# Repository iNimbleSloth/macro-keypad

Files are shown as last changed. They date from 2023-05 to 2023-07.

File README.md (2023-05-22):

# macro-keypad
A small USB macro keypad designed to use Cherry MX or pin compatible switches.

Here’s an accompanying video showing the macro keypad in more detail.

See the use, design and coding on [YouTube](https://www.youtube.com/watch?v=2TVdBebZfKo)
MacroKeypad_square
2023-05-21-14 40 29_square

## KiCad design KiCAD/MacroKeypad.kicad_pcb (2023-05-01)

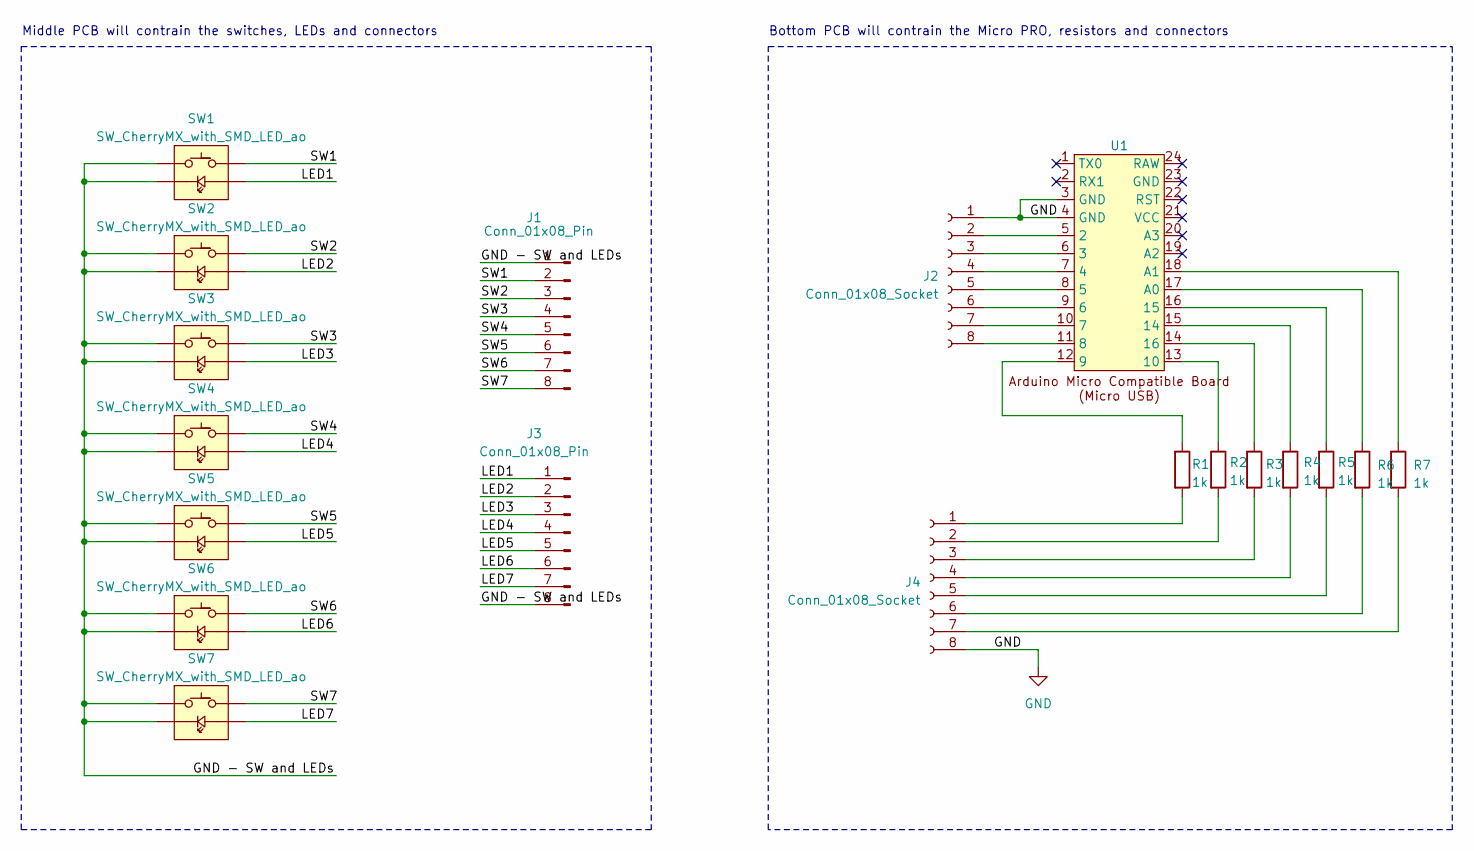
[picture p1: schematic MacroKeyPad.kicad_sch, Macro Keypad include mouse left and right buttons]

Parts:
J1, J3: Conn_01x08_Pin; PinHeader_1x08_P2.54mm_Vertical
J2, J4: Conn_01x08_Socket; PinSocket_1x08_P2.54mm_Vertical
R1, R2, R3, R4, R5, R6, R7: 1k; R_Axial_DIN0207_L6.3mm_D2.5mm_P10.16mm_Horizontal
SW1, SW2, SW3, SW4, SW5, SW6, SW7: SW_CherryMX_with_SMD_LED_ao; SW_Cherry_MX_1.00u_PCB_with SMD LED.kicad_AO
U1: ArduinoMicroCompatibleBoard

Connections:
/GND - SW and LEDs: J1.1, J3.8, SW1.1, SW1.3 (K), SW2.1, SW2.3 (K), SW3.1, SW3.3 (K), SW4.1, SW4.3 (K), SW5.1, SW5.3 (K), SW6.1, SW6.3 (K), SW7.1, SW7.3 (K)
/LED1: J3.1, SW1.4 (A)
/LED2: J3.2, SW2.4 (A)
/LED3: J3.3, SW3.4 (A)
/LED4: J3.4, SW4.4 (A)
/LED5: J3.5, SW5.4 (A)
/LED6: J3.6, SW6.4 (A)
/LED7: J3.7, SW7.4 (A)
/SW1: J1.2, SW1.2
/SW2: J1.3, SW2.2
/SW3: J1.4, SW3.2
/SW4: J1.5, SW4.2
/SW5: J1.6, SW5.2
/SW6: J1.7, SW6.2
/SW7: J1.8, SW7.2
GND: J2.1, J4.8, U1.3 (GND), U1.4 (GND)
unnamed: J2.2, U1.5 (2)
unnamed: J2.3, U1.6 (3)
unnamed: J2.4, U1.7 (4)
unnamed: J2.5, U1.8 (5)
unnamed: J2.6, U1.9 (6)
unnamed: J2.7, U1.10 (7)
unnamed: J2.8, U1.11 (8)
unnamed: J4.1, R1.2
unnamed: J4.2, R2.2
unnamed: J4.3, R3.2
unnamed: J4.4, R4.2
unnamed: J4.5, R5.2
unnamed: J4.6, R6.2
unnamed: J4.7, R7.2
unnamed: R1.1, U1.12 (9)
unnamed: R2.1, U1.13 (10)
unnamed: R4.1, U1.15 (14)
unnamed: R5.1, U1.16 (15)
unnamed: R3.1, U1.14 (16)
unnamed: R6.1, U1.17 (A0)
unnamed: R7.1, U1.18 (A1)

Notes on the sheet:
Bottom PCB will contrain the Micro PRO, resistors and connectors
Middle PCB will contrain the switches, LEDs and connectors

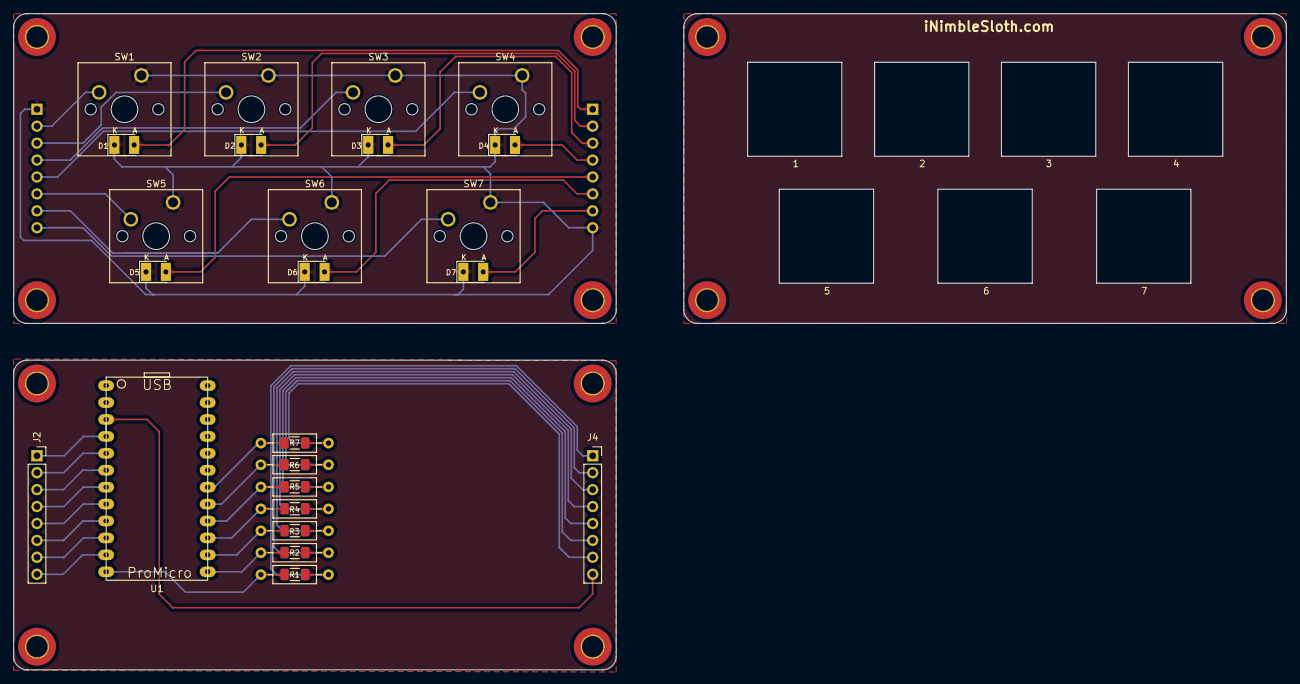
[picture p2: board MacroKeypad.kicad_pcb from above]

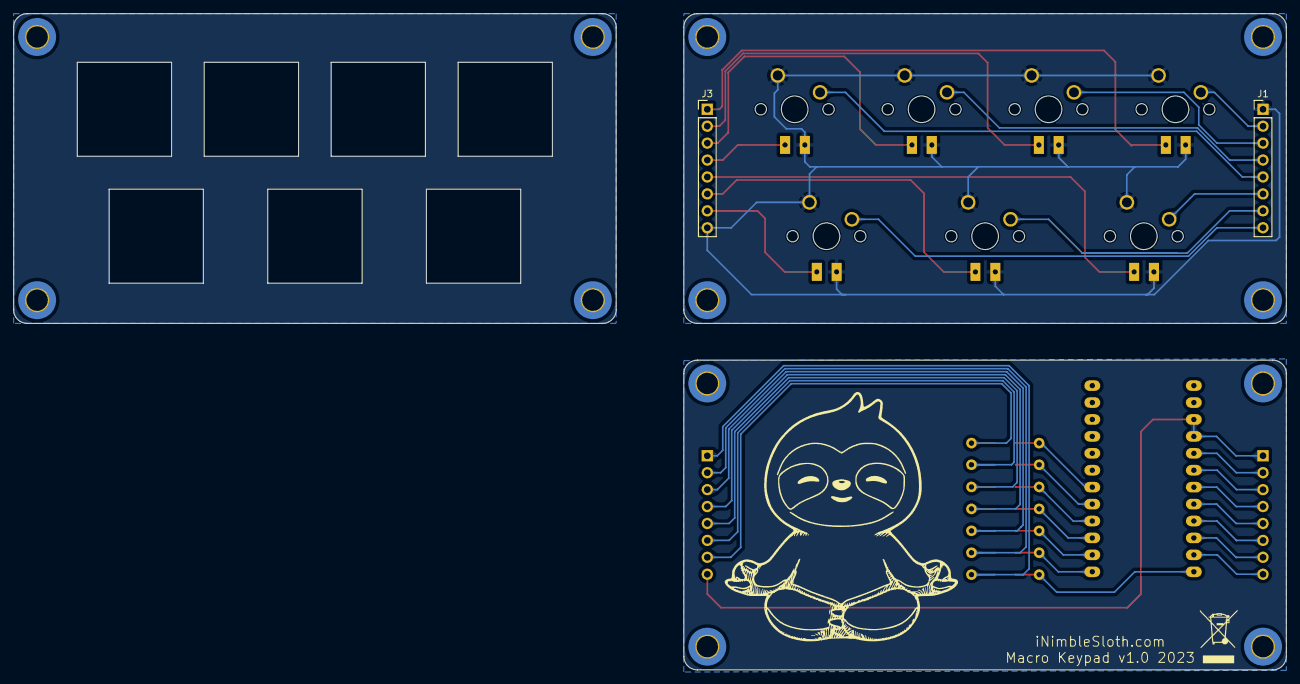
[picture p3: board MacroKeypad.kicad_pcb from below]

Board: 2 copper layers, 191.0 x 98.5 mm, 19 parts (2 on the bottom side), 37 nets.

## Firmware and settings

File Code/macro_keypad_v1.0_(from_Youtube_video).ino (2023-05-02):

 /*  Macro Keypad
  by iNimbleSloth.com
  April 2023
*/
#include <Keyboard.h>
#include <Mouse.h>

//Create names for I/O; SW for input switches & led for LEDs in the switches.
//The Number is the Arduino pin out NOT the PCB pinout!!
int sw1 = 2;
int sw2 = 3;
int sw3 = 4;
int sw4 = 5;
int sw5 = 6;
int sw6 = 7;
int sw7 = 8;
int led1 = 9;
int led2 = 10;
int led3 = 16;
int led4 = 14;
int led5 = 15;
int led6 = 18;
int led7 = 19;

// variables to keep strack of button states
bool copyState = false;       // set initial state of Copy to false, i.e copy key not held down
bool pasteState = false;      // set initial state of paste to false, i.e copy key not held down
bool sw1State = false;        // set initial sate of sw1 to false
bool sw2State = false;        // set initial sate of sw2 to false
bool sw3State = false;        // set initial sate of sw3 to false
bool sw4State = false;        // set initial sate of sw4 to false
//bool sw5State = false;        // set initial sate of sw5 to false
//bool sw6State = false;        // set initial sate of sw6 to false
bool sw7State = false;        // set initial sate of sw7 to false

void setup() {

  Serial.begin(9600);           //serial output used for debugging (not required for release version)

  //setup I/O; SW inputs with internal pull up resistor. LEDs as outputs.
  pinMode(sw1, INPUT_PULLUP);
  pinMode(sw2, INPUT_PULLUP);
  pinMode(sw3, INPUT_PULLUP);
  pinMode(sw4, INPUT_PULLUP);
  pinMode(sw5, INPUT_PULLUP);
  pinMode(sw6, INPUT_PULLUP);
  pinMode(sw7, INPUT_PULLUP);
  pinMode(led1, OUTPUT);
  pinMode(led2, OUTPUT);
  pinMode(led3, OUTPUT);
  pinMode(led4, OUTPUT);
  pinMode(led5, OUTPUT);
  pinMode(led6, OUTPUT);
  pinMode(led7, OUTPUT);
}

//Main program loop starts here.
void loop() {
  //Serial.println("Start of Loop ");

  //SW1
  // IF SW1 is pressed AND the sw1State status is false (i.e. not already pressed), then type text
  if (digitalRead(sw1) == LOW && sw1State == false)
  {
    digitalWrite(led1, HIGH);
    sw1State = true;
    Keyboard.println("Case ");
    Keyboard.println("Create cLibrary acount and add username to contact in Salesforce.");
    Keyboard.println("Send through new technical contact lead.");
    delay(50);
  }
    
  // IF SW1 is released AND the sw3State status is true (i.e. button just released), then turn off the LED on the  button (SW1/LED1)
  if (digitalRead(sw1) == HIGH && sw1State == true)
  {
    digitalWrite(led1, LOW);
    sw1State = false;
    delay(50);
  }
    
  //SW2
  // IF SW2 is pressed AND the sw4State status is false (i.e. not already pressed), then type text
  if (digitalRead(sw2) == LOW && sw2State == false)
  {
    digitalWrite(led2, HIGH);
    sw2State = true;
    Keyboard.println("Created cLibrary acount and added username to contact in Salesforce.");
    Keyboard.println("Sent through new technical contact lead.");
    delay(50);
  }
    
  // IF SW4 is released AND the sw2State status is true (i.e. button just released), then turn off the LED on the snip button (SW2/LED2)
  if (digitalRead(sw2) == HIGH && sw2State == true)
  {
    digitalWrite(led2, LOW);
    sw2State = false;
    delay(50);
  }

  //SW3
  // IF SW3 is pressed and the sw5State status is false (i.e. not already pressed), then press type text
  if (digitalRead(sw3) == LOW && sw3State == false)
  {
    digitalWrite(led3, HIGH);
    sw3State = true;
    Keyboard.println("Case ");
    Keyboard.println("Create academy account.");
    Keyboard.println("Send lead through to quote for training.");
    delay(50);
  }
    
  // IF SW3 is released AND the snipeState status is true (i.e. button just released), then turn off the LED on the snip button (SW5/LED5)
  if (digitalRead(sw3) == HIGH && sw3State == true)
  {
    digitalWrite(led3, LOW);
    sw3State = false;
    delay(50);
  }

  //SW4 
  // IF SW4 is pressed and the sw4State status is false (i.e. not already pressed), then press type text
  if (digitalRead(sw4) == LOW && sw4State == false)
  {
    digitalWrite(led4, HIGH);
    sw4State = true;
    Keyboard.println("Created academy account.");
    Keyboard.println("Sent lead through to quote for training.");
    delay(50);
  }
    
  // IF SW4 is released AND the snipeState status is true (i.e. button just released), then turn off the LED on the snip button (SW4/LED4)
  if (digitalRead(sw4) == HIGH && sw4State == true)
  {
    digitalWrite(led4, LOW);
    sw4State = false;
    delay(50);
  }
    
  //SW5
  // IF SW5 is pressed and the copyState status is false (i.e. not already pressed), then execute Windows COPY command
  if (digitalRead(sw5) == LOW && copyState == false)
  {
    digitalWrite(led5, HIGH);
    copyState = true;
    Serial.println("Windows COPY command START");
    Keyboard.press(KEY_LEFT_CTRL);
    Keyboard.write('c');
    Keyboard.release(KEY_LEFT_CTRL);
    delay(50);
  }
    
  // IF SW5 is released AND the copyState status is true (i.e. button just released), then turn off the LED on the COPY button (SW5/LED5)
  if (digitalRead(sw5) == HIGH && copyState == true)
  {
    digitalWrite(led5, LOW);
    copyState = false;
    Serial.println("Windows COPY command END");
    delay(50);
  }

  //SW6 
  // IF SW6 is pressed AND the pasteState status is false (i.e. not already pressed), then execute Windows PASTE command
  if (digitalRead(sw6) == LOW && pasteState == false)
  {
    digitalWrite(led6, HIGH);
    pasteState = true;
    Serial.println("Windows PASTE command START");
    Keyboard.press(KEY_LEFT_CTRL);
    Keyboard.write('v');
    Keyboard.release(KEY_LEFT_CTRL);
    delay(50);
  }
    
  // IF SW6 is released AND the pasteState status is true (i.e. button just released), then turn off the LED on the PASTE button (SW3/LED3)
  if (digitalRead(sw6) == HIGH && pasteState == true)
  {
    digitalWrite(led6, LOW);
    pasteState = false;
    Serial.println("Windows PASTE command END");
    delay(50);
  }

  // IF SW7 is pressed and the sw7State status is false (i.e. not already pressed), then press execuste Windows DESKTOP command
  if (digitalRead(sw7) == LOW && sw7State == false)
  {
    digitalWrite(led7, HIGH);
    sw7State = true;
    Serial.println("Windows Desktop command START");
    Keyboard.press(KEY_LEFT_GUI);
    Keyboard.write('d');
    Keyboard.release(KEY_LEFT_GUI);
    delay(50);
  }

  // IF SW7 is NOT pressed and the rightClick status is true (i.e. the button has just been released), then release the right mouse button
  if(digitalRead(sw7) == HIGH && sw7State == true)
  {
    digitalWrite(led7, LOW);
    sw7State = false;
    delay(50);
  }

}

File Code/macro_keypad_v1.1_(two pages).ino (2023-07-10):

 /*  Macro Keypad
  by iNimbleSloth.com
  April 2023
*/
#include <Keyboard.h>
#include <Mouse.h>

//Create names for I/O; SW for input switches & led for LEDs in the switches.
//The Number is the Arduino pin out NOT the PCB pinout!!
int sw1 = 2;
int sw2 = 3;
int sw3 = 4;
int sw4 = 5;
int sw5 = 6;
int sw6 = 7;
int sw7 = 8;
int led1 = 9;
int led2 = 10;
int led3 = 16;
int led4 = 14;
int led5 = 15;
int led6 = 18;
int led7 = 19;

// variables to keep strack of button states
bool sw1State = false;        // set initial state of sw1 to false
bool sw2State = false;        // set initial state of sw2 to false
bool sw3State = false;        // set initial state of sw3 to false
bool sw4State = false;        // set initial state of sw4 to false
bool sw5State = false;   	  // set initial state of sw5 to false
bool sw6State = false;        // set initial state of sw6 to false
bool sw7State = false;        // set initial state of sw7 to false
bool page2Status = false;     // set initial state of Page 2 to false (this is a specical case used in toggle function of the button)
int currentSW7State;          // to keep track of the current state of button 7 (special case used in toggle function of the button)
int lastSW7State;             // to keep track of the last state of button 7 (special case used in toggle function of the button)


void setup() {

  Serial.begin(9600);           //serial output used for debugging (not required for release version)

  //setup I/O; SW inputs with internal pull up resistor. LEDs as outputs.
  pinMode(sw1, INPUT_PULLUP);
  pinMode(sw2, INPUT_PULLUP);
  pinMode(sw3, INPUT_PULLUP);
  pinMode(sw4, INPUT_PULLUP);
  pinMode(sw5, INPUT_PULLUP);
  pinMode(sw6, INPUT_PULLUP);
  pinMode(sw7, INPUT_PULLUP);
  pinMode(led1, OUTPUT);
  pinMode(led2, OUTPUT);
  pinMode(led3, OUTPUT);
  pinMode(led4, OUTPUT);
  pinMode(led5, OUTPUT);
  pinMode(led6, OUTPUT);
  pinMode(led7, OUTPUT);
  
  // read in current states of the switches (specical case for SW7 as being used to toggle the state of CTRL)
  currentSW7State = digitalRead(sw7);
}

//Main program loop starts here.
void loop() {
  //Serial.println("Start of Loop ");
  
  lastSW7State = currentSW7State;       //save the last state of button 7
  currentSW7State = digitalRead(sw7);   //read in the current state of button 7

  //SW1
  // IF SW1 is pressed AND the sw1State status is false (i.e. not already pressed), then type text
  if (digitalRead(sw1) == LOW && sw1State == false)
  {
    if (page2Status != true)
    {
      //Serial.println("Page 1 Button 1");
      digitalWrite(led1, HIGH);
      sw1State = true;
      //ENTER YOUR KEYBOARD SHORT CUT FOR PAGE 1 HERE
    }
    else
    {
      //Serial.println("Page 2 Button 1");
      digitalWrite(led1, HIGH);
      sw1State = true;
      //ENTER YOUR KEYBOARD SHORT CUT FOR PAGE 2 HERE

      
    }
    delay(50);
  }
    
  // IF SW1 is released AND the sw3State status is true (i.e. button just released), then turn off the LED on the  button (SW1/LED1)
  if (digitalRead(sw1) == HIGH && sw1State == true)
  {
    digitalWrite(led1, LOW);
    sw1State = false;
    delay(50);
  }
    
  //SW2
  // IF SW2 is pressed AND the sw4State status is false (i.e. not already pressed), then type text
  if (digitalRead(sw2) == LOW && sw2State == false)
  {
    if (page2Status != true)
    {
      //Serial.println("Page 1 Button 2");
      digitalWrite(led2, HIGH);
      sw2State = true;
      //ENTER YOUR KEYBOARD SHORT CUT FOR PAGE 1 HERE

    }
     else
    {
      //Serial.println("Page 2 Button 2");
      digitalWrite(led2, HIGH);
      sw2State = true;
      //ENTER YOUR KEYBOARD SHORT CUT FOR PAGE 2 HERE
    }
    delay(50);
  }
    
  // IF SW2 is released AND the sw2State status is true (i.e. button just released), then turn off the LED on the snip button (SW2/LED2)
  if (digitalRead(sw2) == HIGH && sw2State == true)
  {
    digitalWrite(led2, LOW);
    sw2State = false;
    delay(50);
  }

  //SW3
  // IF SW3 is pressed and the sw5State status is false (i.e. not already pressed), then press type text
  if (digitalRead(sw3) == LOW && sw3State == false)
  {
    if (page2Status != true)
    {
      //Serial.println("Page 1 Button 3");
      digitalWrite(led3, HIGH);
      sw3State = true;
      //ENTER YOUR KEYBOARD SHORT CUT FOR PAGE 1 HERE

      
    }
    else
    {
      //Serial.println("Page 2 Button 3");
      digitalWrite(led3, HIGH);
      sw3State = true;
      //ENTER YOUR KEYBOARD SHORT CUT FOR PAGE 2 HERE
      
    }
    delay(50);
  }
    
  // IF SW3 is released AND the snipeState status is true (i.e. button just released), then turn off the LED on the snip button (SW5/LED5)
  if (digitalRead(sw3) == HIGH && sw3State == true)
  {
    digitalWrite(led3, LOW);
    sw3State = false;
    delay(50);
  }

  //SW4 
  // IF SW4 is pressed and the sw4State status is false (i.e. not already pressed), then press type text
  if (digitalRead(sw4) == LOW && sw4State == false)
  {
    if (page2Status != true)
    {
      //Serial.println("Page 1 Button 4");
      digitalWrite(led4, HIGH);
      sw4State = true;
      //ENTER YOUR KEYBOARD SHORT CUT FOR PAGE 1 HERE
    }
    else
    {
      //Serial.println("Page 2 Button 4");
      digitalWrite(led4, HIGH);
      sw4State = true;
      //ENTER YOUR KEYBOARD SHORT CUT FOR PAGE 2 HERE
    }
    delay(50);
  }
    
  // IF SW4 is released AND the snipeState status is true (i.e. button just released), then turn off the LED on the snip button (SW4/LED4)
  if (digitalRead(sw4) == HIGH && sw4State == true)
  {
    digitalWrite(led4, LOW);
    sw4State = false;
    delay(50);
  }
    
  //SW5
  // IF SW5 is pressed and the sw5State status is false (i.e. not already pressed), then execute Windows COPY command
  if (digitalRead(sw5) == LOW && sw5State == false)
  {
    if (page2Status != true || true)  // FOR MY MACROPAD BUTTON 5 should do the same for both pages
    {
      //Serial.println("Page 1 Button 5");
      digitalWrite(led5, HIGH);
      sw5State = true;
      //Serial.println("Windows COPY command START");
      Keyboard.press(KEY_LEFT_CTRL);
      Keyboard.write('c');
      Keyboard.release(KEY_LEFT_CTRL);
    }
    else
    {
      //Serial.println("Page 2 Button 5");
      digitalWrite(led5, HIGH);
      sw5State = true;
      //KEY PRESSES TO BE SIMULATED FOR PAGE 2 BUTTON 5 GOES HERE
    }
    delay(50);
  }
    
  // IF SW5 is released AND the sw5State status is true (i.e. button just released), then turn off the LED on the COPY button (SW5/LED5)
  if (digitalRead(sw5) == HIGH && sw5State == true)
  {
    digitalWrite(led5, LOW);
    sw5State = false;
    //Serial.println("Windows COPY command END");
    delay(50);
  }
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

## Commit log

2023-05-01 Create KiCAD
2023-07-10 Create macro_keypad_v1.1_(added_2nd_page).ino
    Version 1.1 uses button 7 (sw7) to toggle between two "pages" of buttons. LED 7 is used for feedback as to the currently selected page.
    LED 7 OFF = Page 1 (default upon power on)
    LED 7 ON = Page 2
2023-07-10 Create Codmacro_keypad_v1.1_(two pages).ino
    Button 7 (SW7) toggles between two "pages" of buttons.
    LED 7 gives feedback as to page;
    - LED7 OFF = Page 1 (default upon power on)
    - LED ON = Page 2
2024-08-08 Add files via upload
    Added switch symbol and footprint as per request on YouTube.
